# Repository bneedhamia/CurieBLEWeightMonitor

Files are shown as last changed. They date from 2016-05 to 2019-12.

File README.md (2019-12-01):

# CurieBLEWeightMonitor

NOTE: Intel discontinued the Arduino 101 in 2017. Because of the end-of-life of the Arduino 101, this project is obsolete.

An Arduino/Genuino 101 (Curie) Sketch to continuously report my dog's weight using load sensors
and Bluetooth Low Energy (BLE), and a Node.js Raspberry Pi application to periodically read from the scale
and write the data to a stream at http://data.sparkfun.com.  That is, it's an IoT (Internet of Things) application.

The scale sends the total weight on the scale (plywood top, bed, bed cover, and possibly the dog), as well as the
weight measured by each of the 4 Load Sensors at the corners of the scale.
This data should be sufficient to estimate whether the dog is in or out of the bed, how much the dog weighs,
whether the dog is restless or still, and where on the bed the dog is laying (center of gravity).

See the project blog, beginning at https://needhamia.com/?p=661 for all the details.
## Data Details
The Sketch periodically reports the total weight and weight at each Load Sensor in Kilograms
and as Standard BLE Weight Characteristics.
The total weight and 4 Load Sensor weights are reported as the weights of 5 different BLE Users.
See the Sketch code/comments for details of the timing of the sending of the weights.
## Files
- ProjectDiary.odt = day-to-day diary of the progress of the project. Useful to see how the project unfolded over time.
- CurieBLEWeightMonitor.ino = Arduino 101 Sketch to run on the scale.
- scalegateway = node.js code to upload data from the scale to the cloud via a Raspberry Pi or such.
- WeightScale.fzz = rudimentary Fritzing circuit diagram.
- BillOfMaterials.ods = parts list, with suppliers and prices.
- MechanicalNotes.odp = diagrams of any complicated physical parts.
- ProjectMath.odp = mathematical background to the formulas in the code. Also provides insight into the Load Sensor circuitry.
- Calculations.ods = Spreadsheet of testing and design measurements.
- loadsensorholder.FCStd = FreeCAD file for 3D printing hold-downs for the Load Sensors.
- loadsensorholder.stl = the corresponding STL file, which you can print from a variety of 3D printers.
- centeringguide.FCStd, .stl = FreeCAD and STL files for the nail Centering Guide used to align the top and bottom plywood pieces.

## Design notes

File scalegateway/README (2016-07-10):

This directory contains the files for the Raspberry Pi Node.js script
that reads the weights from the Arduino 101 scale, via BLE, and uploads them
to data.sparkfun.com via WiFi.

See the individual files for more information.

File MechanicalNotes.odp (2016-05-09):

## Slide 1

The Load Sensor

The top piece of plywood rests on the four load sensors

2.7 mm

3mm

5mm

Side view

21mm

8mm

5mm

Bottom view

24mm

The sensor “C” shape (White here) must be supported,

but the (gray here) “T” shape must be free to bend downward, below the “C” shape.

## Side view of the assembled scale (not to scale)

Nail, in center of top plywood circle

top plywood circle

support block

support block

support block

support block

bottom plywood circle

Plastic Centering Guide

## The centering guide

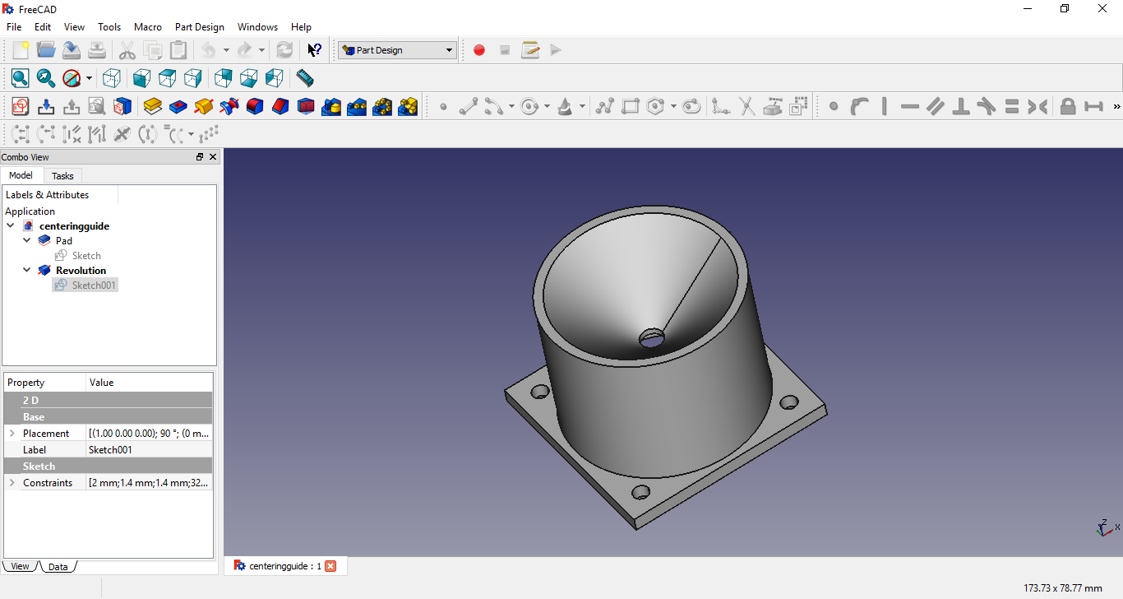
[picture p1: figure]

## Cross Section of Centering Guide

Top plywood circle

  The idea is that when lowering the top plywood circle onto the scale, you can sort-of center it by eye, then the nail and cone will guide you to center the plywood.

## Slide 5

The Load Sensor support block,

which sits underneath the load sensor

See loadsensorholder.FCStd

for hole dimensions.

Holes to mount the block to the plywood base

Note: the block is made of

two thicknesses of the plywood

used to make the top and

bottom of the scale.

Note: the block must be thick

Enough that the circuit connectors

will not interfere with the top

piece of plywood.

Whatever

You like

0.70”

(17.8mm)

Whatever

You like

0.55”

(14mm)

1.5”

(38 mm)

Top view

Front view

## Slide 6

Finding the Center of Gravity

## Marking the Top Plywood Center of Gravity

It's important that the top plywood piece of the scale have a center of gravity that is directly over the center of the rectangle formed by the 4 Load Sensors. Any error in the position of the center of gravity will affect your calibration.

NOTE: because plywood isn't of uniform density (like MDF is), the center of gravity is likely not the center of the circle you cut out. So you have to find the center of gravity.

## Find one line through the center of gravity

One property of the Center of Gravity is that if you suspend the object (the plywood circle) from a point, the Center of Gravity will be directly below it.

Drill a small hole on the rim of the plywood top. Put a nail loosely through the hole and hang a weight on a string from that nail. Both the plywood circle and the weight must hang freely.

Mark the line you've found this way. The center of gravity will be somewhere along it.

## Find a second line through the center of gravity

Drill a second small hole on the rim of the plywood top, about ¼ of the way around the rim from the first hole (but you don't have to be precise). Put a nail through the hole and hang a weight on a string from that nail. Both the plywood circle and the weight must hang freely.

Mark the line you've found this way. The center of gravity will be at the intersection of this line and the first line.

Center of Gravity

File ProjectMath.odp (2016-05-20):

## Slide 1

The scale design uses one Load Cell Amplifier per Load Sensor (4 total).

These slides describe:

1) how to connect 1 load sensor to an amplifier

2) how to calibrate 4 independent load sensors

3) how to calculate weight and center of gravity

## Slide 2

The Load Sensor Circuit

## The Load Sensor circuit

E+ (Vcc)

Black

R1

R1 decreases slightly with weight

S+

Red

Red (S+) voltage should increase with weight

R2

R2 remains constant with weight

E- (GND)

White

## A Wheatstone Bridge

E+ (Vcc)

The Load Sensor

R1

R3

S+

S-

R2

R4

E- (GND)

## An easier way to think about a Wheatstone Bridge: It is two voltage dividers

5V E+

5V E+

R1

R3

V1 S+

V2 S-

R2

R4

GND E-

GND E-

V1 = V2 only if 5V / (R1 + R2) * R2 = 5V / (R3 + R4) * R4. That is, R1:R2 as R3:R4

## Using a Load Cell Amplifier

5V

5V

Tiny differences in V1-V2 are amplified.

A slight change in R1 and R2 causes a slight change in V1, which causes a change in (V1-V2) * 128.

That final value is digitized and reported by the HX711. That value is proportional to the change in R1 and R2, which is proportional to the weight on the Load Sensor.

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
(V1-V2) * 128

## Choosing R3 and R4

5V

5V

Because the Load Sensor's R1 is closely matched to R2, we must choose R3 and R4 to be nearly equal to each other. If they aren't, there will be a large voltage difference between V1 and V2, and the amplified difference will be too large to digitize.

A pair of +/-0.1%, 1K resistors may vary by as much 2 ohms (1 + 1 ohm), so we buy several 0.1% 1K resistors and pick a pair of them that are very close to the same resistance.

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
(V2 – V1) * 128

## Measuring a resistor pair

E+ Amp RED

Measure the difference in a pair of resistors in the following way:

1) Pick two resistors from the set of 1K ohm, 0.1% resistors. Mark or note which ones they are.

2) Put them in this circuit as RA and RB.

3) Measure the Load Cell Amplifier output with no weight on the Load Sensor. Call that Vab.

4) Swap RA and RB

5) Measure the output again. Call that Vba.

6) The error is |Vba – Vab|

Do this with several resistors and pick the pair that has the minimal difference.

Black

White

R1

RA

Red

S+

Amp WHT)

S-

Amp GRN

R2

R4

E- (Amp BLK)

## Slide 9

Calibrating 4 separate load sensors.

This scale design calls for a separate amplifier for each load sensor, letting the Arduino see the value for each separate load sensor instead of mixing the 4 load sensors' output with a Load Sensor Combinator Board.

## Calibrating one Load Sensor

The HX711 library assumes that the resistance of the load sensor

changes linearly with the weight applied to it.

Formula for a line: Y = M * X + B

X is Weight

Y is reported raw value from the amplifier.

Given two {X, Y} pairs, you can calculate M (SCALE) and B (OFFSET):

M = (X2 – X1) / Y2 – Y1)

B = Y1 – M * X1

## Calibrating 4 Load Sensors: put the weight at the center of the rectangle

When a weight W is an equal distance from the 4 Load Sensors A B C and D, each Load Sensor sees ¼ of the weight.

Place a known weight in the center of the scale, and read the values from the Load Sensors A B C and D. Separately record X (W/4), and Y for each Load Sensor.

Repeat the process for at least one more weight.

Then calculate M (SCALE) and B (OFFSET) separately for each Load Sensor.

D

C

W

A

B

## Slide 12

Measuring Weight and Center of Gravity

from the readings from the 4 Load Sensors

## Background: The statics of “Class 1 levers”

The weight on the two support points must sum to the weight placed anywhere between them.

W

W1

W2

W = W1 + W2

Also, as in a seesaw, a fulcrum with two weights, the Moments must sum to zero.

L1

L2

W1

W2

W1 * L1 = W2 * L2

## Calculating weight W and center of gravity {X,Y}

D

C

Given the weights read by the

Load Sensors A, B, C, and D

and knowing the scale dimensions

U and V, calculate X, Y, and W.

W = A + B + C + D

To calculate X and Y, we use a

property of the center of gravity:

that for any line going through the

center of gravity, the Moments on

one side of the line balance (equal)

those on the other side of the line.

V

W

Y

A

X

B

U

## Calculating X

D

C

Imagine a knife-edged fulcrum is

under the line PQ. Because PQ goes

through the center of gravity, the

Moments perpendicular to that line

segment must sum to zero.

AX + DX = C(U-X) + B(U-X)

so

AX + BX + CX + DX = CU + BU

so

X = (C + B) / (A + B + C + D) * U

Q

W

P

A

X

B

U

## Calculating Y

D

C

We calculate Y in the same way

we calculated X:

Imagine a knife-edged fulcrum is

under the line RS. Because RS goes

through the center of gravity, the

Moments perpendicular to that line

segment must sum to zero.

AY + BY = C(V-Y) + D(V-Y)

so

AY + BY + CY + DY = CU + DU

so

Y = (C + D) / (A + B + C + D) * V

V

W

R

S

Y

A

B

## The Dog's center of gravity and weight

What we've measured so far is the weight and center of gravity of the combined plywood top plus Pippa (the dog).

To calculate the location of Pippa's center of gravity and her weight, we have to do one more lever calculation: Imagine a fulcrum at W

T * L1 = P * L2

W = T + P

We know T (plywood weight) from calibration.

We know L1 and W from our calculations from A, B, C, and D.

Find P (Pippa's weight) and L2.

So

P = W – T

L2 = T * L1 / P

From there we can use vector addition to calculate the X and Y of Pippa's center of gravity

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
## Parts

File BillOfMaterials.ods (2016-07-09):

Bill Of Materials for Arduino-Controlled Dog-sized weight scale
Count | Name | Supplier | Part Number | Cost each | Total | Url | Notes
1 | Arduino/Genuino 101 | Sparkfun | DEV-13787 | $30.00 | $30.00 | https://www.sparkfun.com/products/13787 | The Sketch uses the Curie-specific BLE functions.
1 | Wall Adapter Power Supply - 9VDC 650mA | Sparkfun | TOL-00298 | $5.95 | $5.95 | https://www.sparkfun.com/products/298 | Or you could use a USB charger capable of at least 650mA. A USB charger would let you debug the scale without having to take the scale top off.
1 | Raspberry Pi 3 | Sparkfun | DEV-13825 | $39.95 | $39.95 | https://www.sparkfun.com/products/13825 | Version 3 required, for its BLE capability. This is the gateway from the scale to the cloud.
1 | MicroSD Card with Adapter - 16GB (Class 10) | Sparkfun | COM-13833 | $8.95 | $8.95 | https://www.sparkfun.com/products/13833 | For Raspberry Pi 3.
1 | Raspberry Pi Enclosure – Clear | Sparkfun | DEV-12996 | $8.95 | $8.95 | https://www.sparkfun.com/products/12996
1 | Wall Adapter Power Supply - 5.25V DC 2.4A (USB Micro-B) | Sparkfun | TOL-13831 | $7.95 | $7.95 | https://www.sparkfun.com/products/13831 | For Raspberry Pi 3.
4 | Load Sensor - 50kg | Sparkfun | SEN-10245 | $9.95 | $39.80 | https://www.sparkfun.com/products/10245 | One for each corner of the scale. Most people salvage these sensors from an inexpensive bathroom scale.
4 | SparkFun Load Cell Amplifier - HX711 | Sparkfun | SEN-13230 ROHS | $9.95 | $39.80 | https://www.sparkfun.com/products/13230 | Amplifies the Wheatstone Bridge signal for the Arduino
1 | SparkFun Solder-able Breadboard | Sparkfun | PRT-12070 | $4.95 | $4.95 | https://www.sparkfun.com/products/12070
25 | RESISTOR 1K OHM 1/4W 0.1% AXIAL | Digikey | 1KADCT-ND | $0.27 | $6.77 | http://www.digikey.com/product-search/en/resistors/through-hole-resistors/66690?k=1kadct-nd | You ultimately need only 8, but you have to hand select them from a larger set.
1 | a few feet of CAT3 cable (4 wires). 4 times 14 inches | n/a |  | $0.00 | $0.00 |  | separate, stranded wire would probably be fine
1 | Heat Shrink kit | Sparkfun | PRT-09353 | $7.95 | $7.95 | https://www.sparkfun.com/products/9353 | Only a few inches are required, to cover 4 x 3 solder joints
2 | Non-Structural Rated Square Fir Sanded Plywood (Actual: 0.75-in x 4-ft x 4-ft) | Lowes | 154281 | $25.25 | $50.50 | http://www.lowes.com/pd_154281-199-173254___?productId=50080988 | Should have used cheaper plywood. It needs to be thick so it doesn't bend with the dog's weight.
2 | Break Away Headers – Straight, 40 pins | Sparkfun | PRT-00116 | $1.50 | $3.00 | https://www.sparkfun.com/products/116 | You snap off the number you need for 3, 4, or 5 pin connectors
1 | Break Away Headers - Long | Sparkfun | PRT-10158 | $2.95 | $2.95 | https://www.sparkfun.com/products/10158 | For connections between the Arduino female headers and the various connectors
50 | Molex female connecter terminals 22-24 AWG tin | Digikey | 16-02-0102-C | $0.13 | $6.32 | http://www.digikey.com/product-search/en?keywords=16-02-0102-C | These are very useful, so I'd recommend buying 100 of them.
15 | CONN HOUSING 2POS .100 SINGLE | Digikey | WM2800-ND | $0.32 | $4.73 | http://www.digikey.com/product-search/en?keywords=wm2800-nd | You need only 10, but I recommend bying 20
5 | Molex 3 position, 0.100” spacing, single row, Connector Housing | Digikey | 50-57-9003-P | $0.42 | $2.11 | http://www.digikey.com/product-search/en?keywords=50-57-9003-P | You need only 4 but again, these are useful parts. I'd recommend buying 20
15 | Molex 4 position, 0.100” spacing, single row, Connector Housing | Digikey | 50-57-9004-P | $0.43 | $6.44 | http://www.digikey.com/product-search/en?keywords=50-57-9004-P | You need only 12 but I recommend buying 20
1 | Blue Hawk 12-Count #4- 40 x 3/4-in Round-Head Zinc-Plated Slotted-Drive Standard (SAE) Machine Screws | Lowes | 62045 | $1.24 | $1.24 | http://www.lowes.com/pd_62045-37672-605392__ | You need 27. You will need to counterbore the bottom holes for the bolts so the nuts fit – the bolts are chosen to not protrude fromt he bottom of the plywood
 | miscellaneous hookup wire (22 AWG, solid) | Sparkfun |  |  | $0.00 |  | Use Solid hookup wire for the Protoboard circuitry.
 | miscellaneous hookup wire (22 AWG, stranded) | Sparkfun |  |  | $0.00 |  | Use Stranded wire for the wires connecting boards. Stranded wire will flex; solid wire will quickly break when repeatedly flexed.
6 | meters of ABS plastic filament |  |  | $0.35 | $2.10 |  | For the 3D Printed Load Sensor Holders and Centering Guide.
1 | 18-8 Stainless Steel Flat Head Phillips Machine Screw 1/4"-20 Thread, 2-1/4" Length, 25 count | McMaster-Carr | 91771A551 | $11.46 | $11.46 | http://www.mcmaster.com/#91771a551 | Note: Stainless Steel is ROHS compliant (lead free); Zinc plated doesn't seem to be.
1 | ASTM F594 Type 18-8 Stainless Steel Hex Nut 1/4"-20 Thread Size, 7/16" Wide, 7/32" High, 50 count | McMaster-Carr | 92673a113 | $3.30 | $3.30 | http://www.mcmaster.com/#92673a113 | You only need 8, for the Load Sensor holders.
1 | Nail. 2 inches long x 0.1 inch thick |  |  |  | $0.00 |  | Used to center the top Plywood piece, using the Centering Guide. Remember to remove the nail after centering, to avoid breaking the Centering Guide.
 | Calibration weights |  |  |  | $0.00 |  | Weightlifting weight sets can be found for low prices at used-products stores, such as Goodwill in the USA.
Grand Total |  |  |  |  | $295.16
Useful tools
1 | Yardstick compass (beam compass) | Amazon | B003B3P99K | $10.25 | $10.25 | http://www.amazon.com/WoodRiver-Yardstick-Compass/dp/B003B3P99K | For drawing a large circle on the plywood
1 | Crimping Pliers - 28-20 AWG | Sparkfun | TOL-13193 | $29.95 | $29.95 | https://www.sparkfun.com/products/13193

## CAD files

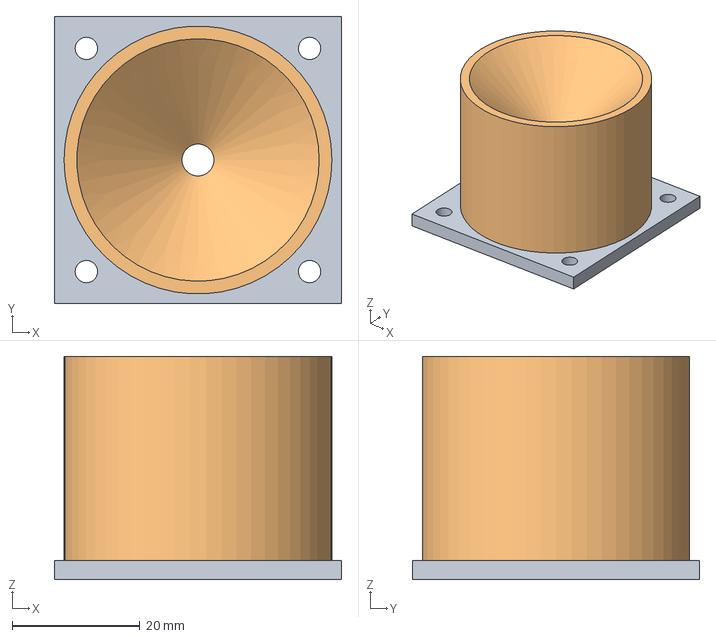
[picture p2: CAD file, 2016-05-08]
centeringguide.FCStd
45.0 x 45.0 x 35.0 mm

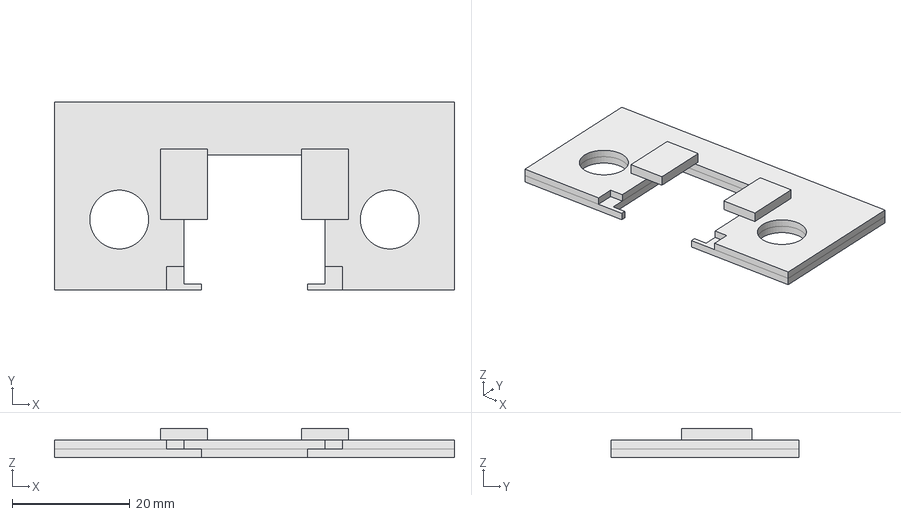
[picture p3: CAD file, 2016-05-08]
loadsensorholder.FCStd
68.0 x 32.0 x 5.00 mm

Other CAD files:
centeringguide.stl
loadsensorholder.stl

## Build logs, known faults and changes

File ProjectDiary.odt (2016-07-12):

# Arduino 101 continuous weight scale Project Diary

Brad Needham

Begun April 3, 2016

Project blog at https://needhamia.com/?p=661

@bneedhamia on Twitter

## Summary

I want to automatically weigh our dog every night while she sleeps in her bed. The weight is measured by an Arduino 101 which reads a set of Load Sensors, then transmits the results via BLE (Bluetooth Low Energy) to a Raspberry Pi gateway, which relays the data to the cloud via WiFi.

Analysis of the data can tell when the dog is in the bed, and weigh only when she's been in bed, at rest, for a while.

## Status

The scale hardware and software are running. It successfully transmits standard BLE Weight measurements of 5 “users”: the total weight on the scale, and the weight of each of the four load sensors. I'm in the process of writing the Raspberry Pi Node.js code to make the Pi a gateway between the BLE scale and the Sparkfun Data warehouse, data.sparkfun.com.

I likely have to recalibrate the scale – I'm not entirely happy with the current calibration.

A MakeZine article about continuously weighing a beehive sounds like a similar project: http://makezine.com/projects/bees-sensors-monitor-hive-health/. It uses https://data.sparkfun.com/ to store its data and make it available to everyone for analysis.

## April 3, 2016 – Initial design, cut bottom plywood circle

I'm assuming a few things to make this possible:

- Her bed is a good place to weigh her. I suppose I could put the scale under her crate, but she spends more time in her bed than in her crate.
- She usually doesn't take toys or other animals to bed, so the maximum minus minimum weight will be her true weight. If she brought things into her bed, the weight measure would be complicated.
- Even though she moves around the room in the night, she spends at least a few minutes asleep in her bed every night, so that's a good time to weigh her.
- Although she sometimes sleeps with her head hanging over the edge of the bed, it never touches the floor. If it did, I wouldn't get a good weight reading.
- I'll have to see whether her bed cover touches the floor. I'm assuming it doesn't.

I've ordered and received parts from Sparkfun (see BillOfMaterials.ods). Helpfully, Sparkfun sells a pair of boards that take most of the work out of the electronics. Also, each load sensor has a maximum reading of 50Kg. That's over 110 lbs, which is over 2 times the weight of our dog. Since there are 4 sensors, which will split the load depending on where the center of gravity is, it seems nicely over-designed to support her weight.

I plan to buy two sheets of plywood: one for the base, that will contain the load sensors and electronics, and one that will sit on top of the load sensors.

The challenge at this point is to design the mechanical parts.

- Each load sensor needs to be supported only on its outside arms; the center arm must be free to bend – that arm is where the strain sensor is attached.
- Each load sensor has a small metal bump on top. The upper piece of wood must rest on all four of these bumps, and must not slip off. I'm not quite sure how to arrange that yet. I suppose I might drill 4 small dents into the upper piece of wood so that it won't slip over the bump.
- To prevent the top piece from slipping off when bumped, I'm thinking of attaching sides to it, so that the top piece is sort of a wooden box lid with sides that go down to part of the lower part.
- The wires that come attached to the load sensors are likely too short, so I'll need to solder-and-heat-shrink some longer wires to them. I'm a little concerned that long wires may pick up electrical noise that may make it difficult to make an accurate reading. Perhaps I can move the load sensors somewhere between the corners of the bottom board and the center, and not have to add extra wire.

Measured our dog's bed: a roughly-circular 41-inch diameter (~20” radius) shape. The wires on each load sensor are about 15 inches from the edge of the sensor to the end of the wire. That makes a roughly 30” square with sensors on the sides, which sounds pretty good.

I worried for a moment that all of the dog, bed, and covers must be inside the rectangle defined by the load sensors, but now I don't think that's true: it doesn't matter to the weight measurement where the weight is, as long as the center of gravity is within the rectangle.

Privacy: Imagining putting per-minute-or-so weight data on a server available to anyone makes me think a moment about what such data could unintentionally reveal: when we go to bed and get up; when she's in boarding (that is, when we're away). Naively it doesn't sound like it could reveal much else.

I measured the dog bed and decided to make a 41” circular scale, with the load sensors near the edge. I realized that when Pippa sleeps against one side of her bed, her center of gravity could be close to the edge. Because of that situation, I need to put the load sensors as close to the outside edge of the circle as I can.

Bought 2 sheets of 4'x4'x3/4” plywood. 1/2” seemed to flex too much; 3/4” didn't flex with the weight I'm planning on.

Using a beam compass I'd purchased a long time ago, I drew a 41” diameter circle on the first plywood sheet, then cut it with a jig saw.

## April 5, 2016 – solder wire extensions

The load sensors come with about 15” of wire attached. I need closer to 26” of wire, so I soldered on another 14” of wire to each wire. I happened to use some CAT3 cable I had lying around, but you could use separate, stranded cable to extend the load sensors' wires.

## April 6, 2016 – Solder headers; puzzle out the circuit

I soldered headers on all the pins of the Load Combinator board and the Load Cell Amplifier board. I did this instead of soldering the wires directly to make it easy to correct wiring errors and to replace a failed part.

Next I wanted to crimp the female connectors onto the load sensors, but was a bit stumped about which pin to connect where. The Load Combinator board pins are labeled B, W, and R, and the load sensor wires are Black, White, and Red, so I could just wire B to Black, etc., but I've seen enough cheap parts that have swapped wires that I'd like to understand the schematic.

So first I measured the resistance of a load sensor. B to R was about 1Kohm, R to W was about 1Kohm, and B to W was about 2Kohm. So the Red wire in the sensor is the center tap between two resistors. Further, as I pushed on the sensor, the resistance between R and B dropped a little, and the resistance between R and W stayed the same. Reading through Sparkfun's Load Cell Amplifier Hookup Guide, I found a description of the load sensor, that matched what I'd seen. So this gives me confidence that I can connect each Load Sensor to the corresponding B, W, and R pins on the Load Combinator board.

## April 7, 2016 – Complete the wiring

I finished crimping all the connectors to various wires. Now the circuit is complete. In summary: I've soldered and heat-shrunk extensions to each of the load sensors' wires; I've soldered in header pins for all the connections on the Load Combinator board and Load Cell Amplifier board; I've crimped 3-pin connectors on the end of each set of 3 wires for each load sensor; I've crimped 4-pin connectors between the Load Combinator and Load Cell Amplifier boards; I've crimped a 4-pin connector onto the wires that go from the Load Cell Amplifier board to the Arduino.

For now I'm using an Arduino Uno, because I want to check that the code works on an Uno before seeing whether I need to do anything to port to Arduino 101. I also decided to put the Arduino on the bottom plywood piece of the scale, along with the other electronics. I'll need to remember to open and vacuum the scale every once in a while, to keep dust from short-circuiting the parts.

I also test layed out the parts on the bottom circle of plywood. Everything looks good. I'm still a bit puzzled about how to keep the load sensors from slipping without epoxying them down.

## April 9, 2016 – design a preliminary support block

I measured the dimensions of the load sensor, documented them in the Mechanical Notes file, and worked out the preliminary design of the block that will support the load sensor and keep the top piece of plywood from pressing on the circuitry (which is rather thick because of the connectors). This preliminary block will allow me to test the rest of the circuit while I think about a more permanent design that will keep the load sensors from slipping over time.

## April 10, 2016 – Assemble and test the scale, discover a problem

Today was a second day of woodworking: I cut the top circular piece of plywood; drilled mounting holes for the Combinator board, the Load Cell Amplifier board, and the Arduino; counterbored holes in the bottom of the plywood base so the board nuts can connect; cut out blocks to support the load sensors (with nothing to hold them in place yet); assembled the whole thing and turned it on.

The great news is that it seems to work, and seems to be wired correctly!

I did a few tests using the Sparkfun HX711 examples, and found a few things:

- The HX711 library assumes a linear change in readings vs. weight (vs. say polynomial). Something is funny, because the code seems to scale the value differently depending on what 'zero' weight is on the scale. That suggests the sensors' values aren't linearly proportional to weight. I'll have to explore this more.
- The position of Pippa's center of gravity on the scale will produce different readings. This is a big problem, since Pippa often sleeps with her head hanging over the edge of her bed.

Moving a 15 pound weight from the center to the 4 corners (right above each of the 4 load sensors) gave readings that differed by 2/3 pound. This tells me the load sensors don't all have the same calibration factor, or perhaps aren't wired identically. This isn't surprising, since each load sensor is labeled with a different calibration factor. This means that as Pippa moves around in bed, the scale will produce different (incorrect) values. I have to explore this more once I get the basic scale calibrated and working properly.

I'm so happy I connected everything with connectors rather than soldering it together, because it looks like I'll need to change the circuit design to accommodate Pippa sleeping in different parts of the bed – that is, with her center of gravity anywhere inside the rectangle defined by the points of the four load sensors.

## April 10-12, 2016 – Calibration and testing

It was very easy to use the HX711 library to read and calibrate the scale. I'm impressed.

I did a series of measurements to calibrate the scale, then to test how accurate it was. These numbers convinced me to redesign the scale to use a separate Load Cell Amplifier for each Load Sensor, so I can calibrate out the differences among them, and as a side benefit, calculate Pippa's center of gravity as she flops about in her bed.

I ordered 3 more Load Cell Amplifiers, checked that I have plenty of the right resistors to build a Wheatstone bridge for each Load Sensor, and ordered a Raspberry Pi to be my BLE to Cloud gateway.

By the way, as I was writing this, Pippa decided to lay down on the scale. The reported weight is 44.3 lbs, which may be about 1 pound high or low.

## April 15, 2016 – how to hold the sensors; ordering parts

I decided a simple way to hold the sensors to the support blocks: friction. I've ordered bolts, nuts, and washers from McMaster-Carr so that the bolts that hold the support blocks to the bottom plywood base also hold washers that press down on the load sensors' sides, keeping them in place. That arrangement should hold up against the slight sideways pressures that the load sensors will be subjected to as Pippa jumps into and out of bed.

I also decided to build the Wheatstone bridge for each load sensor our of 0.1%, 1Kohm resistors. I measured the resistance of the two resistors of one Load Sensor: each was 997ohms. As I pressed on the load sensor (on the support block), the Blue-to-Red resistance dropped by 1ohm, while the White-to-Red resistance remained at 997ohms.

So the other half of the Wheatstone Bridge (the half must build) should contain paired resistors. 0.1% 1K resistors mean that each resistor could be as little as 999ohms (1000 – 0.1% of 1000) or as much as 1001ohms. So the difference between two resistors could be as much as 2ohms, which is a lot. Fortunately, I bought a large number of the resistors, so I should be able to select pairs of resistors that are more closely matched than that (there is some simple combinatoric math that tells me that picking matched pairs should be easy).

## April 17, 2016 – Finished the 4-load-sensor calibration and measurement formulas

ProjectMath.odp now describes how to choose resistors for wiring up a single Load Sensor to a Load Cell Amplifier, and describes how to calibrate the 4 independent Load Sensors, and how to calculate the weight and center of gravity when the scale is running.

A nice side effect of keeping the 4 load sensors separate (rather than using a Load Sensor Combinator board) is that you can get some feel for the size of weight and position errors. This is because the design uses 4 load sensors instead of the minimal 3 load sensors.

In thinking about calculating center of gravity, I realized that the measured center of gravity will be that of Pippa plus the plywood top. For this reason, it will be important to place the plywood top so its center of gravity is at the center of the rectangle formed by the 4 load sensors. It will also be important that the support points of the 4 load sensors form a rectangle, to minimize error.

Oops: I now realize that the weight and center of gravity includes the bed and bed cover. So we'll know Pippa's weight and location only to the extent that we know the location and weight of the bed and bed cover. The moving of the bed and covers will change our reading of Pippa's weight (somewhat). Maybe a bed isn't the best place to measure her weight. Maybe I could just make a short table for her to lie on in the living room with us.

## April 19, 2016 – Rewriting the calculation of center of gravity

I realized that my calculation of the center of gravity was completely wrong, or at least difficult and misleading. So I redid the physics and algebra and came up with a simpler calculation that is more intuitively correct. See ProjectMath.odp for the details.

I marked and drilled a hole in the Center of Gravity of the top plywood circle. Later I can use this mark to center the top plywood circle over the center of the rectangle formed by the four Load Sensors.

The electronic parts have come in, so now I get to rebuild the circuit, using a breadboard instead of the Sparkfun Load Sensor Combinator Board.

## April 20, 2016 – Load Sensor holder Fail

The bolts and nuts came in, so I tried them out with the washers I had from another project. My plan was to place the bolts and washers on either side of each load sensor, with the bolts holding the load sensor support block to the plywood base and (importantly) putting enough pressure on the washers to keep the load sensor from slipping.

That was the theory.

In reality, the bolt head + washer angle puts the top of the bolt head too close to the height of the load sensor's top button – the point of contact with the top plywood circle. So I expect that once the plywood circle presses down on the load sensor, it might start to contact the bolt heads, which would mess up the weight measurement.

So I'm back to ignoring the problem of how to keep the Load Sensors from slipping for now, while I work on the circuit.

## April 21, 2016 – Working out the Load Sensor circuit

To design the circuit, I started by reacquainting myself with the schematic and behavior of the Load Sensor. The Load Sensor is two resistors in series: one resistance lowers when pressure is put on the Load Sensor; the other resistor remains relatively constant. Also the Load Sensor has three wires coming out of it: White, Black, and Red.

I measured the resistance between pairs of Load Sensor wires, with and without pressure on the sensor.

Wires | Unloaded Resistance | Loaded Resistance
Black to Red | 999 ohms | 998 ohms (resistance went down)
Black to White | 1,998 ohms | ignored
White to Red | 999 ohms | 999 ohms (unchanged)

So the schematic should be: E+ --- Black ---- Red (to S+) --- White --- E-

As pressure is put on the Load Sensor, the Black-to-Red resistance should drop, which will cause the voltage at S+ to increase.

Next I want to pick matched-resistance pairs of resistors from the pack of 100 of 1K, 0.1% resistors. I had all kinds of plans on how to measure the resistance to better than my 4-significant-digits multimeter could measure. Finally I realized that I should just wire up random pairs of resistors in a Wheatstone Bridge with a given Load Sensor and Load Cell Amplifier, the read what the zero-load amplifier output is, then swap the two resistors and measure again. The difference will be proportional to the difference in the resistors.

Created a Fritzing diagram of one Load Sensor's Wheatstone Bridge and connection to its Load Cell Amplifier.

## April 24, 2016 – tried the circuit for one Load Sensor

I built out the circuit in the Fritzing diagram – that of one Load Sensor connected to one Load Cell Amplifier – and tested (and corrected) it.

Then I started testing different 1Kohm, 0.1% resistors. I want to find a pair that are well matched. That is, a pair that when used in the circuit produce a zero-load offset that isn't large.

I made many measurements, of the value of 0V (S+ connected to S-, with no external resisitors in the circuit), the value using various combinations of resistors. ...then I discovered I was using the wrong call. I wanted the raw ADC (Analog to Digital Converter) output, which is available via an hx711.read() call. I then fixed the error and started over, documenting the results here.

With no external resistors in the circuit (just the Load Sensor) and with S+ connected directly to S-, there should be a zero voltage at the ADC. The value I read for 0Vis 5720. This makes a lot more sense than the much larger numbers I was reading when using the wrong call.

I also double-checked the circuit: that when I press on the Load Sensor (when external resistors R1 and R2 are in the circuit), the ADC value increases.

I picked 4 resistors, then started comparing the ADC raw value of 2 of them, both as R1 and R2, then swapped as R2, R1. I picked the combination that produced the negative value that was closest to the 0V value (5720). See Calculations.ods, the sheet named Matching Resistors.

I've built the circuit on a solderless breadboard. I noticed that wiggling the various connections produced ADC values that varied by 10,000 or so. So I plan to move the circuit to a soldered circuit before I finish.

I started building the circuit for the second Load Sensor.

## April 26, 2016 – Built the second Load Sensor circuit

I re-layed-out the circuit so all four channels would fit on a half-sized proto board.

I re-tested the first Load Sensor. It seemed ok. I then built the second Load Sensor and Amplifier circuit, then picked two 1k 0.1% resistors in the same way I did for the first Load Sensor.

## April 27, 2016 – Built the third Load Sensor circuit

I started using connectors to connect the power and Arduino pins, so that no long wires will be soldered to the proto board (once I switch to protoboard).

I ran into a few problems with the circuit not reading zero volts properly, then found it was reading the wrong Load Cell Amplifier. I'd forgotten to re-download the Sketch after I switched the code to read from the 3rd Load Cell Amplifier. Found a simple test: unplug the Load Cell Amplifier of interest from the Arduino. If the output reads 0, that's correct. If instead it reads some number, it's reading from the wrong Amplifier.

## April 28, 2016 – Lost caches of parts

I finished finding the resistor pair for the 3rd of 4 Load Sensor circuits, then built most of the 4th Load Sensor circuit.

Frustratingly, I seem to have run out of 4-position Molex connectors. I know I ordered and received 25 of them recently, but I seem to have put them in a “good place” - that is, somewhere that made perfect sense at the time, but that I can't seem to find now. They're hiding along with 25 5-position Molex connectors.

I do have a bad habit of leaving parts in random Sparkfun cardboard boxes. I expect the parts will turn up sooner than new ones would, but it's still frustrating.

(...later, after a shakedown of my workspace...) HA! I had indeed put the missing parts in a random Sparkfun box, with a bunch of random parts.

Finished wiring the last Load Sensor circuit, and started testing resistor pairs for it.

## April 29, 2016 – Soldered one Load Sensor Circuit

I transferred the Upper-Left Load Sensor Circuit (along with the matched load sensor and amplifier) to a Sparkfun PTH-protoboard-30 to keep the behavior of the circuit more stable. Interestingly, the soldered version of the circuit shows a zero-load offset Amplifier output of 45939 compared to the breadboard value of -2081. That change makes it almost pointless to try to find closely matched resistors, if the value will change that much when the circuit is soldered together.

I also noticed that I can get an idea of how closely matched or unmatched a Load Sensor's resistors are based on the Amplifier value when using R3 and R4 vs. when those two resistors are swapped. Suppose I have two resistors, A and B. Measure the amplifier output value when A is R3 and B is R4. Call that Va. Swap the resistors, so that B is R3 and A is R4, then measure the output. Call that Vb. It turns out that the mean of those numbers, (Va + Vb)/2, is what the amplifier output would be if A exactly matched B. That value gives you an idea of how closely matched the corresponding Load Sensor's resistors are.

## April 30, 2016 – Soldered the rest; making connectors and testing

I picked a resistor pair for the last Load Sensor circuit, then transferred the whole circuit to the Protoboard. I made connectors and tested the Upper Left, Lower Left, and Upper Right Load Sensor/Amplifier circuits. One big surprise is that the soldered circuit has a very different zero-load reading than the breadboarded circuit. This difference makes the searching for matching resistors that I did above sort of pointless, but the numbers still look good.

I did have a worry when the Upper Right circuit didn't seem to be working. I read about 5000 units from the Load Cell Amplifier, regardless of the pressure I put on the corresponding Load Sensor. After a little debugging, I found the Vcc wire in the connector from the Load Cell Amplifier to the Protoboard was broken. I replaced that wire and all was well.

## May 1, 2016 – Finished protoboard and connectors

I finished moving the circuit to the Protoboard, then drilled and routed (counterbored) holes for the bolts that will hold the boards onto the bottom plywood circle. Unfortunately, I found the 3/4” bolts I ordered are too short.

## May 2, 2016 – Finished assembly (except for holding down load sensors)

I tried using 1” bolts to mount the circuit boards to the bottom plywood piece, but they were too long. I tried adding 1/4” spacers, but then I have essentially 3/4” bolts, which are too short. So I need to counterbore the holes a little deeper. I'm a little concerned this may weaken the plywood, but I don't think it will.

I need to find a router bit that can counterbore. The one I have doesn't cut in the center disk of the bit, limiting the bore depth to much more shallow than I need.

I assembled the boards using 1” screws, just to get the whole thing together for initial testing. These bolts protrude a bit out of the plywood bottom, but since the scale is on carpet this isn't a big problem.

Did a touch of testing and calibration. It seems to be ok, with more noise than the initial, 1 Load Cell Amplifier circuit had – I'm not sure why that is.

## May 3, 2016 – Found a Forstner bit works; found creep

I checked the router bit I'd used to counterbore the holes and found that its cutting edges don't go to the center: I pretty much wrecked that bit by forcing it down (it's pretty torn up).

Took a 1/2” Forstner bit and test-fit it into the plunge router – it fit! Did a tidy 1/2” deep hole. So I get to disassemble the boards from the plywood, cut new counterbore holes, and reassemble the boards.

Meanwhile, I did a rough calibration and found a few things: 1) all the weights creep some – when I calibrate for real I should let the weights sit on the scale for a day before reading the value, and 2) For some reason the 0 load values (no plywood top on the scale) are way off of expected values. That tells me that either I misweighed the plywood top or that the 0-weight values hadn't settled before I measured. Rechecking those numbers, it looks like I didn't let the values settle – so I need to even let the zero-weight scale sit for a day before reading the values.

Interestingly, ignoring the zero-weight case, the Load Sensors seem relatively linear. I had expected a polynomial/exponential curve to their output, but at least up to 44 lbs it doesn't appear.

Shopped a bit for barbell weight plates for calibration. Found “Gold's Gym 50 lb Olympic Plate Set” for $64 on Amazon (though shipping must be expensive). I bet that's the sort of thing I could buy very cheaply at a second-hand store. ...or I could borrow some.

## May 4, 2016 – Recut the counterbore holes

Disassembled the boards from the plywood base and re-cut the counterbore holes to 1/4” deep using the Forstner bit – it worked great!

## May 5, 2016 – Designing the 3d printed holders for the Load Sensors

I don’t know FreeCAD, but now’s the perfect time to learn. I found a nice tutorial: http://www.freecadweb.org/wiki/index.php?title=Basic_Part_Design_Tutorial, and used those instructions to create the first of the two slabs that will make up the holder. I have a lot of work to do with this design before it’s ready to print.

## May 6, 2016 – First print!

With a friend’s help, I printed the part I designed yesterday. The Toolchain is FreeCAD to Cura (https://www.lulzbot.com/cura) to print on a Lulzbot Taz 5. It worked! The fit to the Load Sensor is good.

I redesigned the part to give the Load Sensor a little more freedom of movement, and added tabs on the top to hold down the Load Sensor. I had no luck creating countersink holes for the flat head, so for the moment I’ve left simple small holes for the shaft of the bolt.

## May 7, 2016 – First Print by myself!

Today I managed to print the second revision of the Load Sensor holder all by myself – I’m so proud! I adjusted the thickness of the tabs to let the T part of the sensor bend more freely; corrected the size of the bolt head holes (it’s radius, not diameter), and added a pair of tabs to hold the sensor down.

There’s clearly something I don’t understand about FreeCAD and Cura, because the working model was about my 5th attempt, each time starting from scratch. The main symptom is that whenever I use Pocket (drill a hole) in FreeCAD, Cura gets completely confused by the resulting model. I found hints that before exporting I should fuse all the components together to elminate redundant and internal edges, but didn’t have any luck (yet) finding how to do that. Luckily I could construct the holder using three layers that stack simply on top of each other. Cura seems happy with that.

If this print works, I’ll be ready to print 3 more and be done printing. Sometime I’ll need to learn more about FreeCAD and Cura and how to print things with pockets, and learn how to make countersink holes in FreeCAD. For now I can do without these features.

Another thing on my mind: I need to decide how to align the center of gravity of the plywood top with the center of the plywood bottom. Any misalignment will translate into calibration error, because the calibration center of gravity won’t be centered on the four Load Sensors.

## May 6, 2016 – Mess with something enough and you’ll break it

The latest Load Sensor holder looks fine, but it was a little wide for the block I plan to bolt it to. So I did just one more revision of the Load Sensor holder design, and it turned out great!

So I jumped ahead to printing 4 of them at once… and had a printing catastrophe. The plastic wasn’t sticking to the bed. After just a few minutes of printing I had a sticky haywire mess of plastic, and canceled the print.

In checking what went wrong, it looks like I accidentally set the fill ratio to 10%, which (for this printer and material at least) is too little.

While the catastrophe was printing, I started designing a guide to help center the top plywood circle over the bottom one. My idea is to drive a nail into the center of the top plywood circle, and attach a plastic cone to the center of the bottom plywood circle. Then when it’s time to assemble the scale, I can get the top close to the center, then the nail-and-code guide should make it easy to slide the top plywood piece onto the bottom guide. The plywood top weight will still be held my the 4 Load Sensors, but the nail and cone should minimize the side-to-side slippage. We’ll see.

The guide cone design eats plastic: because the cone is unsupported, Cura adds a thin support structure. But for a large cone like this, that support structure is significant: over 3 meters of filament to print.

To sum up: 1) Good News: the Load Sensor holder design is finished, 2) Centering Guide design is in progress.

## May 10, 2016 – Assembled Scale Version 2

I did the last of the woodworking to complete the scale, and assembled it.

## May 11, 2016 – Odd calibration results, then not so odd

I modified the Sketch to calculate Average and Standard Deviation for each Load Cell Amplifier so I wouldn't have to do it manually in a spreadsheet. Read out the statistics for a zero-load weight (not even the top plywood piece).

I re-measured the weight of the top plywood circle by weighing myself, then myself holding the top plywood piece, on the bathroom scale. The reading was 18.7 lbs. Unfortunately, the last time I did the same measurement, the weight was 19.2 lbs = ½ lb difference. How can my scale be accurate if the 'calibrated' weights vary so much? I then measured the weight of the top plywood circle using a luggage scale. 8.5kg and 18.7 lbs, which agreed with the bathroom scale. Then I remembered the woodworking has removed wood since I last measured the top plywood cylinder – so the bathroom scale and luggage scale seem accurate enough after all.

So I proceeded with a top plywood scale weight of 8.5kg.

I (with my wife) laid the plywood top circle roughly in the center of the bottom part of the scale, then dropped the nail into the hole in the center of the top plywood circle and wiggled the top plywood circle about a bit until the nail dropped into the center of the centering guide – the centering guide worked perfectly!

I'll leave the plywood top on for a day or two before measuring its weight, to give the Load Sensors a chance to creep. I re-measured my weightlifting weights with the luggage scale: 6.8 kg and 2 weights of 2.2 kg each. The 2.2kg weights are substantially lighter than the 2.4kg I measured a while ago – that's odd.

So I think I'll have to eventually find some more accurate way of measuring my calibration weights. For now I'll use the luggage scale.

## May 12, 2016 – Starting to write the scale software

I wrote the easy code to measure weight by summing the weight from each Load Cell Amplifier. Since Pippa was lying on the scale, For fun I plugged in the first-estimate scale and offset numbers for each Load Cell Amplifier. It reported 31.58 kg total weight on the scale. Subtracting the 8.5 kg weight of the top plywood circle gave me 50.9 lbs, which isn't a bad result for using very rough scale factors and a roughly 44 lb dog. That result should become better when Pippa leaves the scale and gives me a chance to calibrate it.

Adding the center of gravity calculation was easy, because I had the formulas from my blog.

## May 13, 2016 – Bad Load Sensor wiring, BLE programming

I replaced the Arduino Uno with an Arduino 101 and it works fine with no code changes.

In testing zero-load calibration, I noticed one Load Cell Amplifier was reporting wildly differing numbers: from about -14,000 to almost -19,000. Wiggling the wire made substantial differences, while wiggling the other Load Sensors' wires made little difference in their values. Once I got the lower left sensor to read only 4,000 with a standard deviation of about 50. That's twice the standard deviation of the others, which suggests a lot of electrical noise. To test the connector and Load Cell Amplifier, I swapped the lower-left and lower-right Load Sensor connectors. The problem followed the Load Sensor and its wires.

My first suspicion is that the 3-pin molex connector isn't connecting well: I had some trouble building some of those connectors, for example having a wire break. It's possible one of the wires at that connector is broken.

My second suspicion is the Load Sensor itself. I noticed that the end of the lower-left Load Sensor is cracked: the metal at its tip is split at the rivet that holds the top and bottom pieces together.

I cut off the lower-left Load Sensor connector to the board and crimped new pins and connector onto that set of wires. Happily, the new value from the lower-left Load Sensor is more consistent and the standard deviation is consistent with the other sensors – success!

I noticed in looking at the values from the Load Cell Amplifiers (the Load Sensors) that there seems to be a lot of drift as the Amplifiers warm up. So it's important to run the whole circuit for a while before taking the readings for calibration. This warm-up effect may have been what made me think there was a lot of creep (the Load Sensor mechanical movement), when in reality it was just the circuit warming up.

So I turned on the circuit and left the calibration code running for 15 minutes. After 15 minutes the trends were still sliding up or down (dependent on the Load Cell Amplifier) with no end in sight.

After an hour the data seems to vary by 300 to 700 units. I guess that's the accuracy I'll see. Calculating the slope from the initial weight of the top plywood piece, I'm seeing a minimum slope of about 42,000 units/kg. With that slope, 700 units represents about 0.017 kg, which is actually very good stability.

Wrote code to send the gross weight via the Standard BLE Weight Characteristic. For some reason the device wasn't recognized. Need to debug that – probably forgot something simple.

## May 14, 2016 – Writing the software; BLE works

Found that yes, I'd forgotten the ble.begin() that makes the Bluetooth stack work.

Made a pass over the code to clean it up a bit. Added and tested the BLE code to send the total weight – it works!

Ran the calibration code with the plywood top on, and noticed that the Lower Left sensor has a much larger variation (3000 units) that the others (400 units). That sensor has been a problem from the beginning. It's cracked and I should replace it. (later on in the day, realizing that floor vibrations cause noise in the reading, I think the Lower Left sensor may have more variation because it's closer to the desk chair I'm working in.)

Decided to not try to calculate the net dog weight, because doing that requires a history that only the cloud has. Instead the scale will send the gross weight plus the weights measured by the 4 load sensors (as 5 different BLE Weight “Users”).

After a few hours of running I measured the Load Sensor values for the weight of the plywood top. It was pretty stable: down to the few hundreds of units variation. So I'm using those numbers as the calibration numbers for the plywood top. I then put on a “5 lbs” weight, which I've measured at 2.2 kg. I'll let that sit a while then record its Load Sensor values.

A few hours later I came back and found that the readings were very stable until I walked into the room. At first I thought this was because my body increased the electrical noise, but on reflection I realized that the scale is on a wooden floor on the second floor of the building– so the act of me walking around the scale or even shifting my weight in the desk chair next to the scale is likely causing the noise I'm seeing. Little did I know I've built a low-resolution, single-axis accelerometer. I have to think about that to make sure I don't interpret people walking around the scale/bed as the dog being restless in the scale/bed.

## May 15, 2016 – Discovered I've made a seismometer, adding User Ids

In calibrating the latest weights, I stayed out of the upstairs for hours, then dashed up the stairs and copied the last 37 rows of calibration output. Surprisingly (or not surprisingly), the last 3 samples taken varied a lot, and the several readings before those (before I ran up the stairs) are nicely within a few tens of each other. So I'm getting really good calibration numbers now.

Modified the code to add a User Id to the reported weight, and to report user 0 = total kg, user 1 = Upper-left kg, 2 = lower-left, 3 = upper-right, 4 = lower-right. It works fine.

Now all I have to do is finish the calibration and do a tiny bit of Sketch cleanup, and the Arduino Sketch will be complete.

## May 17, 2016 – Calibration Good News; Bad News

Doing more calibration. On the good side, the technique of leaving the room (or floor of the house) empty for ½ hour before dashing up and checking calibration seems to be working well, with very small variations in the calibration numbers. On the bad side, I was puzzling about why two sensors were reporting different weights than the other two, and discovered that the top plywood disk was off center. I think I bumped it at one point. So I really should work out a mechanical way to keep the top disk from slipping – the plastic centering guide doesn't have enough strength to prevent slippage.

Downloaded Noobs, which I plan to install on the Raspberry Pi 3 that I plan to use as a gateway.

## May 18, 2016 – More Calibration subtleties

Now that I have enough weight values to do a few statistics on, I find 1 Standard Deviation of the Scale (slope) values amounts to about 0.2 kg. Interestingly, because my luggage scale is accurate at best to 0.1 kg, each calibration weight's value is +/-0.05 kg. I'm using 4 calibration weights, so the error is 4 * the single weight error, or +/-0.2 kg.

So if I want this to track Pippa's weight as well as a bathroom scale can, I should probably find a way to either borrow a set of calibration weights (hard) or find a scale that's calibrated to something closer to 10 grams (0.01 kg). Alternatively, I could rig up something to weigh the total weight I'm putting on the scale, rather than summing the individual weights (with their individual weight errors). Perhaps I could load a piece of luggage up?

## May 19, 2016 – Completed Calibration for now

Finished the calibration up to 40 lbs. Not great results (about the same .7lbs error), I assume because of 1) I don't know the actual mass of the weights I'm using, 2) the scale doesn't seem to be level – with just the top on the scale, I see two Load Sensors reporting significantly more weight than the other two, 3) I haven't done all of the calibrations using the technique of being out of the room for a few hours, 4) I think the Load Sensors are just cheap and not so linear, 5) there may be issues because the lines between the Load Sensors and the Protoboard aren't shielded.

I still get varying weight depending on where on the scale the weight is. So in that sense it was a waste of money and calibration effort to have a separate Load Cell Amplifier for each Load Sensor. I still hold out hope that if I accurately measure my calibration weights (e.g., on the scale at the vet's) and pay more attention to being out of the room during calibration, I may get better results.

I updated the Bill of Materials. It sums to about $230 for the project, not counting special tools required.

At any rate, the scale software and hardware is complete!

## June 26-27, 2016 – Set up the Raspberry Pi BLE and Node.js

I've successfully set up the Raspberry Pi with Raspbian Linux, updated the Pi BLE stack, installed Node.js, and installed the Node.js BLE package, “noble”. See PiConfig.txt for details.

I'm in the process of redoing the installation, following and updating the instructions in PiConfig.txt.

## June 28-29, 2016 – Writing BLE Node.js code

The scalegateway code is currently an only-slightly-modified version of noble/test.js (needs to be totally rewritten): it reads a properties file, then reads a single weight measurement from the scale. The weight parsing needs work, because it seems to report values that differ from those reported by the Nordic BLE testing app (which I trust).

I've learned that if the BLE Client (scalegateway) exits without disconnecting, the Arduino 101 remains in a non-advertising state which requires a reset to fix.

## July 3, 2016 – Node.js code periodically reads a set of weights

After experimenting quite a bit to learn how to use the Noble library and various features of Javascript, the gateway app seems to, on a timer, find the scale, connect to it, and read a set of weight measurements that make up one weight record. I have to test it a lot more because of two things:

1. There seems to be some sort of dead spot between the time it's read the last weight and the time is starts the next scan for the device, where if I exit the script it leaves the Arduino 101 BLE library in a non-advertising state. I need to track that down and fix it.
2. Twice I've seen the scale reset its sequence of user Ids. It should do that only when it's reset – so is the scale resetting a lot unexpectedly?

## July 4, 2016 – Node.js code uploads! Scale has a few bugs

The scalegateway.js Node.js Raspberry Pi gateway app successfully reads scale data and uploads it to a stream I created on data.sparkfun.com!

The running code has turned up two scale problems:

1. After about 5 minutes of reading from the scale, the scale stops advertising. I had thought this was a bug in the gateway code, but instead it seems to be in the Arduino 101 scale code.
2. Often the scale starts its sequence of readings over from the start – it seems to be skipping readings. Again, I need to check the Arduino 101 code.

So, the scalegateway code seems to be working fine; the Arduino code needs some work.

## July 5, 2016 – Updated Arduino 101 lib = node.js seems to work

Before starting to seriously debug the problems with the Arduino 101 sketch, I updated the Arduino 101 support to the latest released version, 1.0.6, and re-burned the scale Arduino Sketch.

My preliminary run of the node.js code shows the scale seems to be working: no out-of-sequence measurements; no loss of ability to detect the scale. Unfortunately, I also notice that the Pi script hasn't happened to start readings with reading 1 or 3: it seems to always start with reading 4, 0, or 2. So it's possible that there's some nasty timing bug that will appear only if I'm (un)lucky enough to start the node.js script when the Arduino scale is at some unlucky point in its measurements.

On the other hand, it's (more) likely that somebody fixed some BLE bugs in the Arduino 101 library between version 1.0.4 and 1.0.6. I see from the Arduino 101 support commits, at https://github.com/01org/corelibs-arduino101/commits/master, that they fixed a memory allocation bug which could corrupt memory in the earlier version – perhaps that fixed the problems.

To test the timing question, I modified the Arduino Sketch to report a new weight measurement every 2.8 seconds instead of every 3 seconds – that will force the weight reports to slowly slide in time relative to the start of the node.js code to read a weight measurement, which does two useful things: 1) if there is a timing bug, this should help exercise that bug, and 2) it eliminates the case where the node.js code is started at an 'unlucky' time, and always has to wait almost two weight measurement cycles to see one complete cycle – instead, no matter when the node.js code is started, it will tend to wait an average of 1.5 cycles to see a full weight reporting cycle.

I'm going to let the script run for a while and see what happens.

## July 7-8, 2016 Increasing the script running time

After running the script for several hours at a time – followed by it crashing – I made two changes: 1) I refactored the script to reduce the number of Closures (because they’re sometimes a source of memory leaks) and 2) I added an on(‘error’,…) to the http.request (doh!). The first change seems to have reduced the rate at which the heap grows, and the second fixed a silly omission that caused the script to fail whenever a transfer to data.sparkfun.com failed (a few times per day). I should track down the heap growth, but the best way to do that is by installing the Chrome browser on my Pi, which I’m not quite ready to do yet.

The script has been running for a little over 24 hours now, and the heap has grown by about 1MB. A very rough estimate tells me that it might blow up sometime after a few weeks of running continuously – I should be able to restart the Pi at least once a week to avoid that.

Meanwhile I looked at how to make a Linux Service that runs the Node.js script. I haven’t found a definitive guide: the closest thing I’ve found is a combination of http://raspberrywebserver.com/serveradmin/run-a-script-on-start-up.html and reading /etc/init.d/ntp on the Pi as an example. It looks like I’ll need to a) create an /etc/init.d/ shell script to start and stop the service, and b) create a /usr/sbin/ shell script to set up the environment and run the Node.js script. I’m a little puzzled about the environment I need to set up, because Node and Noble are installed in the user pi’s home directory.

In other news I wondered whether the scale is level – if it isn’t that would explain some of the calibration errors. So I checked it with a 2-foot-long spirit level and it (un)fortunately looks level – so that isn’t a source of the over +/-1/2 pound weight error I’m currently seeing. Looking at the graphs of weights from the four Load Sensors, it looks like when I want to calibrate the scale I’ll need to let a weight sit on the scale for over a day before I calculate the calibration values for that weight. I’m considering rewriting the calibration to report calibration values through a custom BLE Service and Characteristic, so that I can write a modified version of the Node.js script that writes the measured values to a .csv file, so that I can do some real calibration analysis.

## July 9, 2016 – the murky world of Raspbian daemons/services

Advice to bloggers: date your blogs. The blog entry mentioned above, about how to run a script at startup, is undated. Similarly, another one talking about Raspbian and /etc/init.d is dated “Dec 31” with no year. After banging my head against the wall trying to write the arcane details of an /etc/init.d script, I found several StackOverflow messages that suggest that Raspbian /etc/init.d has been obsoleted by Systemd. “man systemd” on my Raspbian Jessie does give a manual page, so it sounds like it's installed.

https://www.axllent.org/docs/view/nodejs-service-with-systemd/ (dated – thank you! - 31 december 2015 makes it sound easy to run a node.js script as a service. I'll dig into that next.

On the good side, the current Node.js script ran nonstop and without the heap growing out of control. I stopped it manually after 2 days, to work on making it a daemon.

Other interesting news: As I moved a 15lb weight around the scale, I realized something: that as I move a weight along a line between diagonally-opposite Load Sensors (UL and LR or LL and UR), the weights seen by the other two Load Sensors should match each other: any difference means either the calibration is incorrect or the load sensor is acting strangely. This means that I probably should perform calibration by placing a known weight at the center of the scale (as I do now), then place it directly over each Load Sensor in turn – that should give me the data I need to choose better calibration constants.

## July 10, 2016 – deciphering Linux systemd and systemctl, et Voila!

I adapted the instructions in the axllent.org page above. It gave a good start, and after reading a few manual pages and fixing a few typos in both the axllent page and my service description, my service was running automatically at boot!

“man 5 systemd.service” describes options in a service file.
“man 5 systemd.unit” provides the field names common to all Units (a Service is a Unit).
“man systemctl” describes the command to install and start services.

That wasn't hard at all (ok, it took an afternoon). Once I knew it was working, I moved the Pi and the Scale to Pippa’s bed. The scale is now uploading real Pippa-weight data to Sparkfun

## July 11, 2016 – debugging

It turns out that the Pi script stopped uploading about 12:30am – only a few hours after it started. Unfortunately by the time I checked /var/log/syslog, the moment of failure had been deleted (as old messages in that file are), but a series of messages suggest the issue:

Jul 11 06:46:02 raspberrypi scalegateway[729]: DEBUG Skipping scan: previous scan is still busy. Connected: true, Subscribed: false.

Jul 11 06:47:02 raspberrypi scalegateway[729]: DEBUG Skipping scan: previous scan is still busy. Connected: true, Subscribed: false.

Jul 11 06:48:02 raspberrypi scalegateway[729]: DEBUG Skipping scan: previous scan is still busy. Connected: true, Subscribed: false.

So it looks like the app connected to the scale, then didn't notice that it disconnected – or remained connected far too long. Curiously, that's the symptom I get when I'm running the Pi with the scale out of range: it connects, then never seems to see any notifications. I'm restarting everything and seeing how long it runs before problems.

## Next steps:

- See what the scale reveals about Pippa’s up to while we sleep.

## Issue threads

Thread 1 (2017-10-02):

check for time passage doesn't handle rollover properly

bneedhamia, 2017-10-02:
The line
if (now - previousWeightTimeMs > MS_PER_WEIGHT_READING) {
should instead read
if ((long) now - previousWeightTimeMs) > MS_PER_WEIGHT_READING) {
to match the pattern described in https://playground.arduino.cc/Code/TimingRollover

This bug may cause some problems after a few days of running, when millis() overflows.

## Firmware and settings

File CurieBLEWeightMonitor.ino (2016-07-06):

/*
 * Dog Bed Weight Scale for Arduino/Genuino 101.
 * 
 * This Sketch periodically reports, through BLE, the weight on the bed
 * and the weight sensed by each of its four Load Sensors.
 * This data provides enough information for a cloud service to calculate
 * when the dog is in or out of the bed and where on the bed the dog
 * is lying (center of gravity), which may be used to infer restlessness.
 * 
 * 
 * Parts Required.  See BillOfMaterials.ods for the full list.
 * - 4 load sensors
 * - 1 proto board that converts the Load Sensors into Wheatstone Bridges
 *   by adding two resistors to each Load Sensor circuit.
 * - 4 Load Cell Amplifier boards (HX711), one per Load Sensor
 * - 1 Arduino 101 (for sending measurements via BLE)
 * 
 * BLE (Bluetooth Low Energy) interface:
 * - The scale appears as a standard BLE Weight Scale device.
 * - It reports that it supports multiple Users
 *   (that is, multiple people weighing themselves).
 * - It reports the weight of 5 "Users", in the following sequence:
 *   User 0 = total weight (kg) on the scale, including the plywood top.
 *   User 1 = weight (kg) measured by the Upper-Left Load Sensor.
 *   User 2 = weight (kg) on the Lower-Left Load Sensor.
 *   User 3 = weight (kg) on the Upper-Right Load Sensor.
 *   User 4 = weight (kg) on the Lower-Right Load Sensor.
 *   You may or may not see it report a User 5 weight on reset - that value
 *   is quickly replaced by one of the others.
 *   Because all these "User" weights share one BLE Characteristic,
 *   each User's weight is reported for a few seconds before it is overwritten
 *   by the next one.
 * 
 * To Use:
 * - Calibrate:
 *   - Run this Sketch with CALIBRATE_SCALE uncommented.
 *   - Let the scale warm up (1/2 hour or so).
 *   - Take everything off the scale, including the top plywood circle.
 *   - Ideally, leave the room for 10 minutes to gather data that isn't
 *     affected by the vibration of the floor.
 *   - Record the values for zero-load.  Those are the Offset values.
 *   - Measure the weight of the plywood top with a bathroom scale.
 *   - Place the Plywood top on the center of the scale.
 *   - wait some time (perhaps a day) to accomodate Load Sensor Creep.
 *   - As above, leave the room for 10 minutes.
 *   - Record the values for the weight of the plywood top / 4
 *   - Measure the weight of a known weight, such as an exercise weight.
 *   - Place the weight on the center of the scale.
 *   - wait some time (perhaps a day) to accomodate Load Sensor Creep.
 *   - Leave the room as above.
 *   - Record the values for the plywood top + the known weight / 4
 *   - Repeat this process for a set of various weights,
 *     Especially weights that are approximately the weight of your dog.
 *   - Using the known weights and corresponding values,
 *     estimate the Scale value for each load sensor.  See Calculations.ods
 *     
 * - Run:
 *   - Comment out CALIBRATE_SCALE.
 *   - Set *_OFFSET and *_SCALE to the values you calculated above.
 *   - Start the Sketch.
 *   - Read the reported weights, etc. using a BLE device.
 *   - Typically you'll want to use a BLE-to-WiFi gateway
 *     (such as a Raspberry Pi 3) to send the data to a cloud
 *     data warehouse such as http://data.sparkfun.com
 *     
 * For debugging the BLE communication, I like the Nordic BLE phone apps:
 * https://play.google.com/store/apps/details?id=no.nordicsemi.android.mcp
 * https://play.google.com/store/apps/details?id=no.nordicsemi.android.nrftoolbox
 *     
 * Copyright (c) 2016 Bradford Needham, North Plains, Oregon, USA
 * @bneedhamia, https://www.needhamia.com
 * Licensed under the GPL 2, a copy of which
 * should have been included with this software.
 */

#include "HX711.h"     // https://github.com/bogde/HX711 Load Cell Amp library
#include <CurieBLE.h>  // Arduino 101 BLE library.
// 80 column marker follows:
//345678901234567892123456789312345678941234567895123456789612345678971234567898

/*
 * USER_* - BLE "User" Ids for our reported weights.
 * We report multiple weights per measurement as the weights of 5 Users
 * 
 * USER_TOTAL = The User Id representing the total weight on the scale.
 * USER_UL = The User Id representing the weight on the Upper-left Load Sensor.
 * USER_LL = the same for the Lower-Left Load Sensor.
 * USER_UR = the same for the Upper-Right Load Sensor.
 * USER_LR = the same for the Lower-Right Load Sensor.
 * 
 * NUM_USERS = the number of different "Users" we report.
 * 
 * USER_RESET = the User Id indicating that the scale has been reset.
 *   Not considered one of the regularly-reported users.
 */

const uint8_t USER_TOTAL = 0;
const uint8_t USER_UL = 1;
const uint8_t USER_LL = 2;
const uint8_t USER_UR = 3;
const uint8_t USER_LR = 4;
const uint8_t NUM_USERS = 5;
const uint8_t USER_RESET = NUM_USERS;

/*
 * Advertised name of our BLE device (the scale).
 * You can change this to whatever you want,
 * as long as the gateway knows the name.
 */
const char *BLE_LOCAL_NAME = "K9 Kilos";

/*
 * CALIBRATE_SCALE = uncomment this line to report raw
 *  Load Cell Amplifier values for calculating calibration.
 * Comment out this line to run the normal scale software.
 */
//#define CALIBRATE_SCALE 1

/*
 * Calibrated values of the linear equation for each set of
 *   Load Cell Amplifier + Load Sensor + Protoboard resistors.
 * You will need to recalibrate if you replace a Load Sensor,
 *   a Load Cell Amplifier board, or any Protoboard resistors.
 *   
 * UL_OFFSET = zero-load offset for the Upper Left Load Sensor,
 *   calculated from CALIBRATE_SCALE readings with nothing,
 *   not even the top plywood circle, on the scale.
 * UL_SCALE_KG = scale from Amplifier units to kg for that Load Sensor.
 *   That is, number of Amplifier reading units per Kilogram.
 *   Calculated from CALIBRATE_SCALE and a spreadsheet. See Calculations.ods
 * 
 * LL_* = Same for Lower Right Load Sensor.
 * UR_* = same for Upper Right
 * LR_* = same for Lower Right
 */

const long UL_OFFSET = 19907L;
const long LL_OFFSET = -22697L;
const long UR_OFFSET = -61289L;
const long LR_OFFSET = -90326L;

const float UL_SCALE_KG = 48119.272;
const float LL_SCALE_KG = 48164.727;
const float UR_SCALE_KG = 54308.909;
const float LR_SCALE_KG = 49765.818;

/*
 * Dimensions of the Load Sensor rectangle.
 * For calculating center of gravity.
 * Measured by hand from the assembled scale.
 * 
 * SCALE_MM_X = width (millimeters) between
 *   the Lower-Left and Lower-Right Load Sensor tops.
 * 
 * SCALE_MM_Y = height (millimeters) between
 *   the Lower-Left and Upper-Left Load Sensor tops.
 */
const float SCALE_MM_X = 708.0f; // (measured 706 and 710)
const float SCALE_MM_Y = 709.0f; // (measured 710 and 708)

/*
 * MS_PER_WEIGHT_READING = time (ms) for each reading the scale weight.
 *   That is, the time per record of data eventually uploaded to the cloud.
 *   NOTE: must be divisible by (NUM_USERS + 1); that is: 6.
 *   The shorter this time is, the more data will be uploaded.
 *   The longer this time is, the more likely we'll miss some movement.
 *   During BLE testing (with no uploading) you probably want to set this
 *   to a under 1 minute (for example, 18000L);
 *   When uploading data to a service, you probably want to set this
 *   to at least a minute (60000L).
 *   If you find your gateway is missing data, increase this number.
 * 
 * MS_PER_WEIGHT_REPORTED = time (ms) the BLE Weight value will remain unchanged  
 *   before it's replaced by a new BLE value.  Necessary because each
 *   weight reading from the scale produces 5 different weights (see USER_*),
 *   which share a single BLE Characteristic.
 *   
 *   NOTE: we add one reporting interval to the reading interval
 *   so that we don't miss reporting something because of minor delays.
 *   
 *   NOTE: I've set the time to not be evenly divisible by 60 seconds
 *   so that the scalegateway.js Node.js script will not synchronize
 *   to the rate of updating - that way there won't be a worst-case starting
 *   time for the script.  I'm doing this mainly to see if there's a timing
 *   bug in the BLE library, but it's handy to prevent a script started
 *   at an unlucky time from always having to wait for almost 2 measurement
 *   cycles to pick up all 5 measurements of one cycle.
 */
const unsigned long MS_PER_WEIGHT_READING = 16800L; // 16.8 seconds = 2.8 seconds/report
const unsigned long MS_PER_WEIGHT_REPORTED = MS_PER_WEIGHT_READING
  / (NUM_USERS + 1);

/*
 * SAMPLES_PER_WEIGHT = number of raw values to average
 *   per reading from a given Load Sensor.
 *   The higher this number, the less noise will appear in readings.
 *   The lower this number, the quicker the readings will occur,
 *   which will make the scale more accurate when the dog is moving.
 */
const int SAMPLES_PER_WEIGHT = 5;

/*
 * I/O pins:
 *
 * PIN_HX711_UL_* = CLock and Data pins for the Upper Left Amplifier.
 *    Upper Left as you look down on the scale and the Arduino is in
 *    the lower-center.
 * PIN_HX711_LL_* = same for Lower Left
 * PIN_HX711_UR_* = same for Upper Right
 * PIN_HX711_LR_* = same for Lower Right
 */
const int PIN_HX711_UL_CLK = 2;
const int PIN_HX711_UL_DOUT = 3;
const int PIN_HX711_LL_CLK = 4;
const int PIN_HX711_LL_DOUT = 5;
const int PIN_HX711_UR_CLK = 6;
const int PIN_HX711_UR_DOUT = 7;
const int PIN_HX711_LR_CLK = 8;
const int PIN_HX711_LR_DOUT = 9;

#ifdef CALIBRATE_SCALE
/*
 * SAMPLES_PER_READING = number of samples per calibration reading.
 * values[] = individual readings to do statistics on.
 */
const int SAMPLES_PER_READING = 40;
float values[SAMPLES_PER_READING];
#endif

/*
 * ulHx711 = controller for the Upper Left HX711 Load Cell Amplifier.
 * llHx711 = Same for Lower Right Load Sensor.
 * urHx711 = same for Upper Right
 * lrHx711 = same for Lower Right
 */
HX711 ulHx711(PIN_HX711_UL_DOUT, PIN_HX711_UL_CLK);
HX711 llHx711(PIN_HX711_LL_DOUT, PIN_HX711_LL_CLK);
HX711 urHx711(PIN_HX711_UR_DOUT, PIN_HX711_UR_CLK);
HX711 lrHx711(PIN_HX711_LR_DOUT, PIN_HX711_LR_CLK);

/*
 * The BLE Objects we use to send data.
 * We send a Standard BLE "Weight Scale" Service,
 *   just like a BLE bathroom scale.
 * See https://developer.bluetooth.org/gatt/services/Pages/ServicesHome.aspx
 * for constants and encoding of BLE data for various purposes.
 * 
 * ble = root of our BLE Peripheral (Server; the Arduino)
 * bleWeightService = BLE service to transmit the total weight on the scale.
 * bleWeightFeature = the features supported by this weight device.
 *   The '4' = 4 bytes are required to store the (32-bit) value.
 * bleWeightMeasurement = the weight measurement itself.
 *   The '4' = 4 bytes are required to store the value:
 *   1 byte of flags, 2 bytes of weight, and 1 byte of User Id.
 */

BLEPeripheral ble;
BLEService bleWeightService("181D"); 
BLECharacteristic bleWeightFeature("2A9E", BLERead | BLENotify, 4);
BLECharacteristic bleWeightMeasurement("2A9D", BLERead | BLENotify, 4);

/*
 * *_kg = Weights (kg) read from each load sensor.
 * total_kg = total weight (kg) of everything currently on the scale,
 * including the top plywood circle.
 */
float ul_kg;
float ll_kg;
float ur_kg;
float lr_kg;

float total_kg;

/*
 * total_cog_mm_x/y = Center of gravity (millimeters) of
 * everything currently on the scale, including the top plywood circle,
 * dog bed, dog bed cover, and possibly the dog.
 */
float total_cog_mm_x;
float total_cog_mm_y;

/*
 * previousWeightTimeMs = Time (ms since reset) of the
 *   most recent weight reading.
 * Used to control how often we measure new Load Sensor values.
 * 
 * weightReportTimeMs = Time (ms since reset) of the
 *   most recent BLE report of weight.  Used because we report multiple
 *   "User" weights per weight reading.
 * weightReportUserId = BLE User Id of the most recent BLE report of weight.
 *   See USER_*.
 */
unsigned long previousWeightTimeMs;
unsigned long weightReportTimeMs;
uint8_t weightReportUserId;


void setup() {
  Serial.begin(9600);

#ifdef CALIBRATE_SCALE
  // On Arduino 101, wait for the PC to open the port.
  while (!Serial);
  
  Serial.print(F("Calibrating, "));
  Serial.print(SAMPLES_PER_READING);
  Serial.println(F(" Samples per row."));

  // This line is formatted so you can import into a spreadsheet
  Serial.print(F("LL Average,LL Std Dev,"));
  Serial.print(F("UL Average,UL Std Dev,"));
  Serial.print(F("UR Average,UR Std Dev,"));
  Serial.println(F("LR Average,LR Std Dev"));

#else
     
  /*
   * Load the calibrations into each Amplifier object.
   * For the linear equation Y = MX + B,
   *   where X = weight and Y = Load Cell Value,
   *   set_scale() sets M,
   *   set_offset() sets B.
   */

  ulHx711.set_scale(UL_SCALE_KG);
  ulHx711.set_offset(UL_OFFSET);

  llHx711.set_scale(LL_SCALE_KG);
  llHx711.set_offset(LL_OFFSET);

  urHx711.set_scale(UR_SCALE_KG);
  urHx711.set_offset(UR_OFFSET);

  lrHx711.set_scale(LR_SCALE_KG);
  lrHx711.set_offset(LR_OFFSET);

  /*
   * Set the previous weight reading and reporting time to 0
   *   sothat we will immediately read and start reporting the weight.
   * Set the UserId so that the next UserId reported will be User 0.
   *   See USER_*.
   */
  previousWeightTimeMs = 0L;
  weightReportTimeMs = 0L;
  weightReportUserId = NUM_USERS;

  // Setup BLE (Bluetooth Low Energy)
  ble.setLocalName(BLE_LOCAL_NAME);
  ble.setAdvertisedServiceUuid(bleWeightService.uuid());
  ble.addAttribute(bleWeightService);
  ble.addAttribute(bleWeightFeature);
  ble.addAttribute(bleWeightMeasurement);

  // Make an initial measurement so we have something to report.
  measure();
  
  /*
   * Initialize our BLE Characteristics from that measurement
   * so that they have a value when we begin.
   * Note: this USER_RESET value will be overwritten almost immediately.
   *   Consequently, the gateway may not see it before it changes.
   */
  setBleWeightFeature();
  setBleWeightMeasurement(USER_RESET, total_kg);

  // Start the BLE radio
  ble.begin();

#endif

}


void loop() {

#ifdef CALIBRATE_SCALE

  delay(2000);

  /*
   * Read and report the average and Standard Deviation for each load sensor.
   * Formatted to paste the output into a spreadsheet.
   */
    
  reportStatistics(&llHx711);
  Serial.print(F(","));
  reportStatistics(&ulHx711);
  Serial.print(F(","));
  reportStatistics(&urHx711);
  Serial.print(F(","));
  reportStatistics(&lrHx711);
  Serial.println();
  
#else

  unsigned long now = millis();

  // If it's time to process a sample, do it.
  
  if (now - previousWeightTimeMs > MS_PER_WEIGHT_READING) {
    previousWeightTimeMs = now;

    /*
     * Force the weight reporting to start over, with the first user,
     * and to do the first report after the first reporting interval.
     * This keeps the reporting and the measuring in sync.
     */
    weightReportUserId = NUM_USERS;
    weightReportTimeMs = now;

    // read the weight and make all the calculations.
    measure();

    Serial.print(total_kg, 2);
    Serial.print(F(","));
    Serial.print(total_cog_mm_x);
    Serial.print(F(","));
    Serial.print(total_cog_mm_y);
    Serial.println();
  }

  /*
   * Each weight reading produces NUM_USERS different reports.
   * If it's time to report a new weight, do it.
   */
  if (now - weightReportTimeMs > MS_PER_WEIGHT_REPORTED) {
    weightReportTimeMs = now;

    ++weightReportUserId;
    if (weightReportUserId >= NUM_USERS) {
      weightReportUserId = 0;
    }

    // report the appropriate weight, based on the User Id.
    if (weightReportUserId == USER_TOTAL) {
      setBleWeightMeasurement(USER_TOTAL, total_kg);
      
    } else if (weightReportUserId == USER_UL) {
      setBleWeightMeasurement(USER_UL, ul_kg);
      
    } else if (weightReportUserId == USER_LL) {
      setBleWeightMeasurement(USER_LL, ll_kg);
      
    } else if (weightReportUserId == USER_UR) {
      setBleWeightMeasurement(USER_UR, ur_kg);
      
    } else if (weightReportUserId == USER_LR) {
      setBleWeightMeasurement(USER_LR, lr_kg);
      
    } else {
      // we get here only if there's a programming error.
      setBleWeightMeasurement(0xFF, 300.0);
    }
  }
  
#endif
}


/*
 * Perform one set of measurements:
 * - total_kg (weight)
 * - total_cog_mm_* (center of gravity)
 */
void measure() {

  // Read the weight (kg) from each Load Sensor
  ul_kg = ulHx711.get_units(SAMPLES_PER_WEIGHT);
  ll_kg = llHx711.get_units(SAMPLES_PER_WEIGHT);
  ur_kg = urHx711.get_units(SAMPLES_PER_WEIGHT);
  lr_kg = lrHx711.get_units(SAMPLES_PER_WEIGHT);

  /* 
   * Calculate the weight of everything on the scale:
   * top plywood circle, bed, bed cover, and possibly the dog.
   */
  total_kg = ll_kg + lr_kg + ul_kg + ur_kg;

  /*
   * Calculate the center of gravity of everything on the scale.
   * For the formula derivation, see the blog at https://needhamia.com/?p=750
   */

  total_cog_mm_x = SCALE_MM_X * (ur_kg + lr_kg) / total_kg;
  total_cog_mm_y = SCALE_MM_Y * (ul_kg + ur_kg) / total_kg;
}


/*
 * Initializes our BLE Characteristic
 * that describes what features our Weight device provides.
 */
void setBleWeightFeature() {
  unsigned long val = 0;          // field value
  unsigned char bytes[4] = {0};   // field value, encoded for transmission.
  
  /*
   * Flags.
   * 
   * bit 0 = 0 means no Time stamp provided.
   * bit 1 = 1 means multiple scale users are supported.
   * bit 2 = 0 means no BMI supported.
   * bits 3..6 = 7 means 0.01 kg resolution (that says nothing about accuracy).
   * bits 7..9 = 0 means height resolution unspecified.
   * bits 10..31 are reserved and should be set to 0.
   */

  val |= 0x0 << 0;
  val |= 0x1 << 1;
  val |= 0x0 << 2;
  val |= 0x7 << 3;
  val |= 0x0 << 7;

  // BLE GATT multi-byte values are encoded Least-Significant Byte first.
  bytes[0] = (unsigned char) val;
  bytes[1] = (unsigned char) (val >> 8);
  bytes[2] = (unsigned char) (val >> 16);
  bytes[3] = (unsigned char) (val >> 24);

  bleWeightFeature.setValue(bytes, sizeof(bytes));
}


/*
 * Sets our BLE Characteristic
 * given a weight measurement (in kg) and
 * the "User" the weight corresponds to.  0xFF = unknown user.
 * 
 * See https://developer.bluetooth.org/gatt/characteristics/Pages/CharacteristicViewer.aspx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
 *  for details of the encoding of weight in BLE.
 */
void setBleWeightMeasurement(uint8_t userId, float weightKg) {
  unsigned char flags = 0;      // description of the weight
  uint16_t newVal = 0;          // field value: the weight in BLE format
  unsigned char bytes[4] = {0}; // data, encoded for transmission.
  
  /*
   * Set the flags:
   * bit 0 = 0 means we're reporting in SI units (kg and meters)
   * bit 1 = 0 means there is no time stamp in our report
   * bit 2 = 1 means User ID is in our report
   * bit 3 = 0 means no BMI and Height are in our report
   * bits 4..7 are reserved, and set to zero.
   */

  flags |= 0x0 << 0;
  flags |= 0x0 << 1;
  flags |= 0x1 << 2;
  flags |= 0x0 << 3;

  // Convert the weight into BLE representation
  newVal = (uint16_t) ((weightKg * 1000.0 / 5.0) + 0.5);

  /*
   * Because we are a continuous, periodic measurement device,
   * we set the BLE value and notify any BLE Client every time
   * we make a measurement, even if the value hasn't changed.
   * 
   * If instead we were designed to keep a BLE Client informed
   * of the changing value, we'd set the value only if the value changes.
   */

  bytes[0] = flags;

  // BLE GATT multi-byte values are encoded Least-Significant Byte first.
  bytes[1] = (unsigned char) newVal;
  bytes[2] = (unsigned char) (newVal >> 8);

  bytes[3] = userId;

  bleWeightMeasurement.setValue(bytes, sizeof(bytes));
}

#ifdef CALIBRATE_SCALE
/*
 * Reports calibration statistics for the given Load Cell Amplifier.
 * pHx = points to the corresponding Load Cell Amplifier controller.
 */
void reportStatistics(HX711 *pHx) {
  float average;        // simple mean of values[]
  float stddev;         // standard deviation from the mean.

  // Collect a set of readings.
  for (int i = 0; i < SAMPLES_PER_READING; ++i) {
    values[i] = pHx->read();
  }

  // Calculate the Average (Mean)
  average = 0.0f;
  for (int i = 0; i < SAMPLES_PER_READING; ++i) {
    average += values[i];
  }
  average /= (float) SAMPLES_PER_READING;

  /*
   * Calculate the standard deviation:
   * the average of the squares of the differences from the Mean.
   */

  stddev = 0;
  for (int i = 0; i < SAMPLES_PER_READING; ++i) {
    stddev += (values[i] - average) * (values[i] - average);
  }
  stddev /= (float) SAMPLES_PER_READING;
  stddev = (float) sqrt(stddev);

  // Output the results, in a form to import into a spreadsheet.
  Serial.print(average, 1);
  Serial.print(F(","));
  Serial.print(stddev, 1);
}
#endif

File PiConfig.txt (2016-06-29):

Configuration of my Raspberry Pi 3 for Node.js BLE development
Brad Needham

Install Raspbian:
Install Noobs on a 16GB MiniSD card for the Pi.
Connect the Pi to an HDMI monitor, keyboard, and mouse.
Connect the Pi to power.
Select Raspbian.
Click WiFi and choose the hotspot to connect to and its password.
Click Install.
Wait for Raspbian to install and reboot.
Once it reboots, it will come up as a graphical interface, auto-logged in as pi.

Setup Raspberry Preferences:
menu / preferences / Raspberry Pi Configuration...
Select the Localization tab
 Locale: USA English
 Timezone: US Pacific
 Keyboard: US English
 WiFi: US
 Click OK
Agree to reboot.

(Re)Setup the Wifi:
Click the networking icon: the two-screen icon in the upper right of the screen.
Wait for it to scan for Access points.
Click on the one you want to connect to.
Enter the password for that WiFi access point.
Wait for the WiFi icon to appear, then wait for that icon to become steady (vs. blinking).

Force update of the date and time, so that network browsing will work:
$ sudo ntpd -qg
Double-check that the date and time in the upper-right of the screen is now correct.
Open the Web Browser (earth and pointer icon) and check that you can view www.google.com

Set up git and clone the CurieBLEWeightMonitor repository:
$ git config --global user.name "your name"    (use your first and last name)
$ git config --global user.email yourEmail@wherever  (use your email address)
$ cd Documents
$ git clone https://github.com/bneedhamia/CurieBLEWeightMonitor

Update the Bluetooth support package, bluez.  The instructions below are a combination of:
- https://learn.adafruit.com/install-bluez-on-the-raspberry-pi/installation
- http://www.jaredwolff.com/blog/get-started-with-bluetooth-low-energy/
Browse to http://www.bluez.org/download/
Click on the link under "User Space Bluez Package" labeled something like bluez-5.40.tar.xz
Wait for that download to complete.
$ cd Downloads
$ tar xvf bluez-5.40.tar.xz
$ rm bluez-5.40-tar.xz
$ mv bluez-5.40 ~
$ cd ~/bluez-5.40
$ sudo apt-get update  (this takes several minutes)
$ sudo apt-get install -y libusb-dev libdbus-1-dev libglib2.0-dev libudev-dev libical-dev libreadline-dev
$ ./configure
$ make >~/make.log 2>&1  (this takes several minutes. Examine ~/make.log for errors.)
$ sudo make install
Reboot.

Just as JaredWolff says, the install didn't copy gatttool. Test and fix that:
$ cd bluez-5.40 (or whatever your bluez version is)
$ sudo ls -l /usr/local/bin/gat*
ls: cannot access /usr/local/bin/gat*: No such file or directory
$ sudo cp attrib/gatttool /usr/local/bin/

Check that the Bluetooth service is installed and running:
$ systemctl status bluetooth
  bluetooth.service - Bluetooth service
   Loaded: loaded (/lib/systemd/system/bluetooth.service; enabled)
   Active: active (running) since Sun 2016-06-26 15:45:31 PDT; 10min ago
     Docs: man:bluetoothd(8)
 Main PID: 716 (bluetoothd)
   Status: "Running"
   CGroup: /system.slice/bluetooth.service
           └─716 /usr/local/libexec/bluetooth/bluetoothd

Test whether you can read a BLE gatt from a BLE device:
Make sure your BLE device is turned on, then:
$ sudo hcitool lescan
LE Scan ...
98:4F:EE:0D:04:B1 K9 Kilos
98:4F:EE:0D:04:B1 (unknown)
^C to exit the scan
$ sudo gatttool -b 98:4F:EE:0D:04:B1 -I    (use the BLE Mac address of your device)
> connect
Attempting to connect to 98:4F:EE:0D:04:B1
Connection successful
> char-desc
handle: 0x0001, uuid: 00002800-0000-1000-8000-00805f9b34fb
handle: 0x0002, uuid: 00002803-0000-1000-8000-00805f9b34fb
handle: 0x0003, uuid: 00002a00-0000-1000-8000-00805f9b34fb
handle: 0x0004, uuid: 00002803-0000-1000-8000-00805f9b34fb
handle: 0x0005, uuid: 00002a01-0000-1000-8000-00805f9b34fb
handle: 0x0006, uuid: 00002803-0000-1000-8000-00805f9b34fb
handle: 0x0007, uuid: 00002a04-0000-1000-8000-00805f9b34fb
handle: 0x0008, uuid: 00002800-0000-1000-8000-00805f9b34fb
handle: 0x0009, uuid: 00002800-0000-1000-8000-00805f9b34fb
handle: 0x000a, uuid: 00002803-0000-1000-8000-00805f9b34fb
handle: 0x000b, uuid: 00002a9e-0000-1000-8000-00805f9b34fb
handle: 0x000c, uuid: 00002902-0000-1000-8000-00805f9b34fb
handle: 0x000d, uuid: 00002803-0000-1000-8000-00805f9b34fb
handle: 0x000e, uuid: 00002a9d-0000-1000-8000-00805f9b34fb
handle: 0x000f, uuid: 00002902-0000-1000-8000-00805f9b34fb
> char-read-hnd 0001
Characteristic value/descriptor: 00 18 
> exit

Next we'll install Node.js

DON'T install the package 'node', because that's an old packet radio app
that has nothing to do with Node.js

Remove the existing installation of Node.js:
$ sudo apt-get --purge remove node
$ sudo apt-get --purge remove nodejs-legacy
$ sudo apt-get --purge remove nodejs
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

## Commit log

2016-04-03 added Bill Of Mateials and started the Project diary
    [BillOfMaterials.ods]
2016-04-06 updated diary; bill of materials
    [BillOfMaterials.ods]
2016-04-08 finished the electrical circuit
    [BillOfMaterials.ods]
2016-04-09 Mechanical sketch for the load sensor and its support block; updated Bill of Materials and diary
    [BillOfMaterials.ods]
2016-04-11 more woodworking; assembled and tried out the scale
    [BillOfMaterials.ods]
2016-04-13 added the calibration spreadsheet (notes); calibrated and tested the accuracy of the scale
    [ScaleCalibrationFirstTry.ods]
2016-04-18 Redesigning to use four Load Cell Amplifiers
    [ScaleCalibrationFirstTry.ods]
2016-04-22 Worked out the Wheatstone Bridge to connect a Load Sensor to a Load Cell Amplifier; Added a Fritzing diagram of one channel
    [WeightScale.fzz]
2016-04-25 Built and tested the first Load Sensor Amplifier circuit, with paired resistors
    [Calculations.ods, ScaleCalibrationFirstTry.ods, WeightScale.fzz]
2016-04-27 Added the second Load Sensor to the circuit
    [Calculations.ods, WeightScale.fzz]
2016-04-28 built the 3rd Load Sensor circuit; Haven't chosen the paired resistors for it yet.
    [Calculations.ods]
2016-04-29 built the last Load Sensor circuit; in the middle of choosing resistors for it.
    [Calculations.ods]
2016-04-30 Transferred one Load Sensor circuit to a soldered protoboard
    [Calculations.ods]
2016-05-01 Finished soldering; started making connectors and testing the soldered circuits
    [Calculations.ods]
2016-05-02 soldering is finished; mounting the boards to the plywood base
    [Calculations.ods]
2016-05-03 completed circuit assembly and did an initial test.
    [Calculations.ods]
2016-05-04 calculated slope; observed a few things about it.
    [Calculations.ods]
2016-05-06 started designing the Load Sensor holders in FreeCAD
    [loadsensorholder.FCStd]
2016-05-07 2nd try at the Load Sensor hold-down plastic part
    [loadsensorholder.FCStd]
2016-05-07 more refined Load Sensor holder - still needs work
    [loadsensorholder.FCStd]
2016-05-07 Adjusted the size of the cylindrical holes a bit
    [loadsensorholder.FCStd]
2016-05-07 Load Sensor holder works for one Load Sensor; made a couple little tweaks
    [loadsensorholder.FCStd, loadsensorholder.stl]
2016-05-08 Load Sensor holder design complete. Working on the Centering Guide design.
    [centeringguide.FCStd, centeringguide.stl, loadsensorholder.FCStd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]
2016-05-12 version 2 scale is running! I'm in the middle of calibrating it.
    [Calculations.ods]
2016-05-13 Calculated a rough calibration to get started; wrote the code to measure the total weight on the scale and total weight's center of gravity.
    [Calculations.ods]
2016-05-14 Now sends (poorly calibrated) weight in kg as a Standard BLE Weight Characteristic.
    [Calculations.ods]
2016-05-15 calibrating continues
    [Calculations.ods]
2016-05-16 Arduino 101 sketch now reports total weight and weight on each Load Sensor. Still calibrating.
    [Calculations.ods]
2016-05-18 more calibration
    [Calculations.ods]
2016-05-20 Scale hardware and software are now complete. The next step is to build the BLE to WiFi gateway.
    [BillOfMaterials.ods, Calculations.ods]
2016-05-23 added Pi config
    [PiConfig.txt]
2016-06-07 Updated Pi conifiguration - starting over
    [PiConfig.txt]
2016-06-07 Starting the second try for BLE
    [PiConfig.txt]
2016-06-27 Installed Node.js, but having trouble loading noble from root
    [PiConfig.txt]
2016-06-27 Successfully reading the raw bytes of the weight measurement. Too early to check in code.
    [PiConfig.txt]
2016-06-29 Node.js and noble (Node.js BLE library) are now working and the setup instructions are corrected
    [PiConfig.txt]
2016-06-30 first checkin of very very early Raspberry Pi Node.js Gateway code - not ready to use
    [BillOfMaterials.ods]
2016-07-03 corrected user ID flag in Weight Measurement.
    [CurieBLEWeightMonitor.ino]
2016-07-05 the Node.js code successfully uploads to data.sparkfun.com; need to fix a couple bugs in the Arduino code that prevent the script from running for very long.
    [piconfig.txt]
2016-07-06 just a few little tweaks. Working well with Arduino 101 BLE library 1.0.6
2016-07-07 refactored to attempt to reduce/eliminate memory leaks. The previous version crashed with a socket error afer about 11 hours.
2016-07-09 made a few minor documentation changes - very minor
    [BillOfMaterials.ods]
2016-07-10 The Node script now runs at boot on my Raspberry Pi! Next stop: Pippa's bed
    [piconfig.txt, scalegateway.cfg]
2016-07-11 put the scale under Pippa's bed. The whole project is working
2019-12-01 Arduino 101 was discontinued in 2017
